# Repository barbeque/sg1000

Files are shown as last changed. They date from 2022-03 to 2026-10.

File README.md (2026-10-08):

The Soggy-1000 logo

Soggy-1000 is an open-source clone of the Sega SG-1000 home videogame system. The eventual goal of the project is to produce a copy of the SG-1000 main console, and the SK-1100 keyboard, so that the software made for the related Sega SC-3000 home computer can be preserved and enjoyed.

## License
The Soggy project is licensed under [the Creative Commons Attribution-NonCommercial 4.0 license](https://creativecommons.org/licenses/by-nc/4.0/).

If you want to build and sell a handful of these systems to use up a "minimum board order," let me know. I'll probably be okay with it!

## Sub-Projects
This repository contains multiple KiCad projects that are related to the overall Soggy project. These are:

 * `keyboard`: An implementation of the SK-1100 keyboard, using modern key switches (Under development)
 * `cartridges/romcart`: An implementation of a bare-bones (ROM-only) cartridge for SG-1000 (Tested, working)
 * `cartridges/basic-iiib`: An implementation of the SEGA BASIC Level IIIB cartridge, used for testing purposes in order to make sure cartridges can take over the entire memory map (Tested, working)

## Other Projects
Other builders have made projects that work with the Soggy! I can't take credit for them. Please visit their repos:

 * [`soggy-case`](https://github.com/kvanderlaag/soggy-case): A 3D-printed case for the Soggy v0.4 and onwards.

Thank you to everyone who has built something for the Soggy!

## Assembly Guide and BOM
Please match the BOM with the appropriate version - the files here in master are currently post-v4 improvements and some parts may be missing or changed their values when compared with the ones in `sg1000-v0.4.bom.csv`

TODO

All solder jumpers should be left as they are from fabrication. They were meant solely so that prototype features could be removed if they didn't work out instead of spinning a new board.

## Programmer's Guide
The Soggy is basically identical to the existing SG-1000, with the addition (in v0.3 and onwards) of memory mapping hardware. This hardware allows programmers to take advantage of the full 32k of main RAM on the system.

TODO: Memory map diagram

TODO: Use IOW + $10 to set it

TODO: Address will change soon to improve compatibility later

## Special Thanks
The following people helped me figure out some aspect of the SG-1000, fixed a bug in my hardware, or otherwise contributed.

 * Enri for providing [SC-3000 and SG-1000 schematics](http://www43.tok2.com/home/cmpslv/Sc3000/EnrSC.htm)
 * Chartreuse for spotting a bug with the latch responsible for page switching
 * Nick Hook from SC-3000 Survivors helped with providing diagrams, pictures, and SF-7000 information
 * Fabio Dalla Libera (sms power) helped with the M1 transistor
 * asynchronous (sms power) also helped with the M1 transistor

## Version History
# v0.5 (in development)
This version contains experimental features.

 * Wider holes on the boot ROM socket footprint, to accept a Textool/AliExpress-style ZIF socket for easier ROM changes during development
 * 1206 ferrite bead on video path to prevent colour burst noise

# v0.4 (in testing)
This version is in active development and may not be suitable for testing yet.

 * /JOY_SEL signal connected to keyboard edge, allowing keyboard 8255 to force polling of joysticks when row 7 of matrix is requested.
 * Converted to DIP Z80 from PLCC, to allow cheaper AliExpress parts to be used rather than expensive new PLCC Z80 part. New DIP Z80s are also still available from Digi-Key, Mouser, etc.
 * Debounce circuit on NMI pin using a Schmitt trigger (design from [this Tynemouth Software blog entry](http://blog.tynemouthsoftware.co.uk/2022/07/how-the-mini-pet-works-debouncing.html), thank you)
 * Weird overpour onto expansion edge fixed, as were some missing silkscreens for '574 and '04
 * Rudimentary support for Sega Genesis/Mega Drive controllers. No mode switching, so it is a similar limitation to Master System games on the Genesis.
 * Trim pot for fine tuning of TMS9918 input clock (and therefore colourburst/Z80/sound clock.) Can be replaced with a simple wire link if you are feeling brave.

# v0.3
Many new features added on the base of the v0.2, and some bugs fixed. This was intended to be the first public release, and is recommended for most people.

 * /IORD and /IOWR signals (IORQ + WR/RD) synthesized and passed to cartridge port. This prevented the SF-7000 from working, as did an I/O map collision with the keyboard. Both problems are now fixed.
 * The full 62256 SRAM is wired up, providing 32K of work RAM to the system. The first 8K are accessible without touching the memory management unit; the second 8K can be switched between four "pages." This should allow Sega BASIC and many other titles relying on SC-3000 functions to work. Previous boards had a 2K mod, matching the SC-3000, but this was not tested.
 * An onboard BIOS ROM socket has been added, which runs when a cartridge is not inserted (detected through the "B2" pin on the cartridge slot, which is usually connected to B1 inside cartridges)

Known bugs:
 * /JOY_SEL is not connected to the keyboard edge
 * Load input on memory management 74ls573 is inverted and doesn't work

# v0.2
 * SK-1100 keyboard edge connector added.
 * Sound chip-induced lockup under /M1 fixed.
 * Extremely weak video signal fixed.
 * Backwards controller ports fixed.
 * Experimental debounce cap on "pause" button added.
 * Reset button added.
 * USB power connector shield grounded.
 * Several problems with sporadic interrupts and waits fixed by adding pull-ups.

Known bugs:
 * /JOY_SEL is not connected to the keyboard edge

# v0.1
Initial release.

Known bugs:
 * Too many to list.

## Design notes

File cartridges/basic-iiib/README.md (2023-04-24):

This folder contains the kicad source files to construct a clone of the Sega SC-3000 BASIC IIIB cartridge that uses UM61512 SRAM instead of the original DRAM, which makes it also compatible with the SK-1100-equipped SG-1000.

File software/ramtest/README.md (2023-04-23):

# RAM tester
This program is meant to be burned to a cartridge ROM and run on a Soggy-1000 clone system. It runs a few simple tests, first doing a check for mirroring to establish the total amount of RAM installed into the system, and then performs a test of the Soggy's page switching functionality. It is not exhaustive nor necessarily indicative of hardware faults.

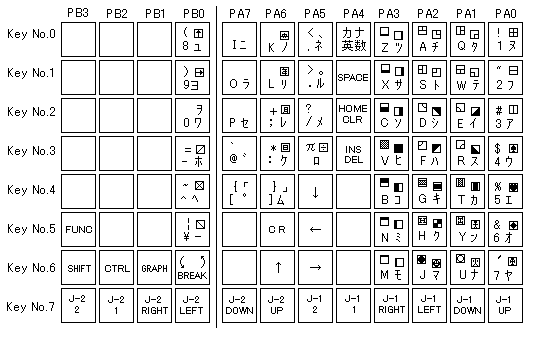
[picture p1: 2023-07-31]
software/shared/references/enri-keymatrix.png

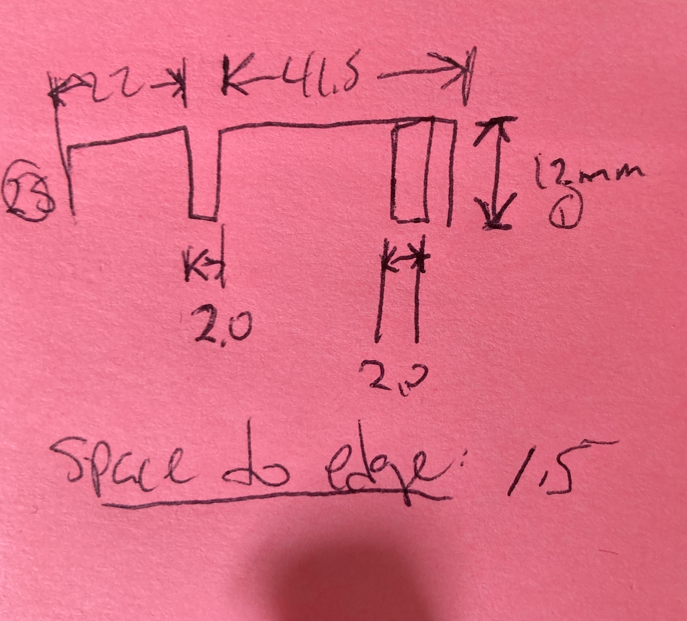
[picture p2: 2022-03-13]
References/mark-iii-expansion-edge.jpg

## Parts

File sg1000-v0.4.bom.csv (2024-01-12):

Customer Reference | Component Name | Value | Footprint | Part Number | Quantity | Description
Soggy: C1, C2 | C | 0.1µF | Capacitor_SMD:C_0805_2012Metric_Pad1.15x1.40mm_HandSolder | 1276-1099-1-ND | 2 | Unpolarized capacitor
Soggy: C3 | C_Polarized_Small_US | 22µF | Capacitor_THT:CP_Radial_D5.0mm_P2.50mm | 493-1037-ND | 1 | Polarized capacitor, small US symbol
Soggy: C4, C9, C16, C100 | C_Small | 0.1µF | Capacitor_SMD:C_0805_2012Metric_Pad1.18x1.45mm_HandSolder | 1276-1099-1-ND | 4 | Unpolarized capacitor, small symbol
Soggy: C5 | C_Polarized_Small_US | 220µF | Capacitor_THT:CP_Radial_D6.3mm_P2.50mm | 493-15121-ND | 1 | Polarized capacitor, small US symbol
Soggy: C6 | C_Polarized_Small | 10µF | Capacitor_SMD:C_0805_2012Metric_Pad1.18x1.45mm_HandSolder | 1276-1298-1-ND | 1 | Polarized capacitor, small symbol
Soggy: C7, C8 | C_Small | 33pF | Capacitor_SMD:C_0805_2012Metric_Pad1.15x1.40mm_HandSolder | 732-7817-1-ND | 2 | Unpolarized capacitor, small symbol
Soggy: CV1 | C_Trim_Small | 0-20pF | LeadedSolder:Tayda_Variable_Trimmer_Cap |  | 1 | Trimmable capacitor, small symbol
Soggy: D1 | D | D | Diode_THT:D_A-405_P7.62mm_Horizontal | 641-1310-1-ND | 1 | Diode
Soggy: D2 | LED | LED | LED_THT:LED_D3.0mm | 1497-1022-ND | 1 | Light emitting diode
Soggy: F1 | Fuse | 2A | Fuse:Fuse_0805_2012Metric_Pad1.15x1.40mm_HandSolder | 2315-FCC20202AATPCT-ND | 1 | Fuse
Soggy: J1 | USB-B1HSB6 | USB-B1HSB6 | USB-B1HSB6:OST_USB-B1HSB6 | ED2983-ND | 1
Soggy: J2 | RCJ-017 | RCJ-014 | Jacks:CUI_RCJ-017 | CP-1403-ND‎ | 1
Soggy: J3 | RCJ-017 | RCJ-013 | Jacks:CUI_RCJ-017 | CP-1402-ND‎ | 1
Soggy: JOY1, JOY2 | DB9_Female | DB9_Female | LeadedSolder:A-DS 09 A-KG-T2S | AE10968-ND | 2 | 9-pin female D-SUB connector
Soggy: Q1 | Q_NPN_EBC | 2n4401 | Package_TO_SOT_THT:TO-92_Inline_Wide | 2N4401TFCT-ND | 1 | NPN transistor, emitter/base/collector
Soggy: Q1c1 | Q_PNP_EBC | 2n3906 | Package_TO_SOT_THT:TO-92_Inline_Wide | 641-1946-ND | 1 | PNP transistor, emitter/base/collector
Soggy: R1 | R_Small_US | 100Ω | Resistor_SMD:R_0805_2012Metric_Pad1.15x1.40mm_HandSolder | RMCF0805JT100RCT-ND | 1 | Resistor, small US symbol
Soggy: R2, R9 | R_Small_US | 560Ω | Resistor_SMD:R_0805_2012Metric_Pad1.20x1.40mm_HandSolder | RMCF0805JT560RCT-ND | 2 | Resistor, small US symbol
Soggy: R3 | R_Small_US | 47kΩ | Resistor_SMD:R_0805_2012Metric_Pad1.15x1.40mm_HandSolder | RMCF0805JT47K0CT-ND | 1 | Resistor, small US symbol
Soggy: R4 | R_Small_US | 1kΩ | Resistor_SMD:R_0805_2012Metric_Pad1.15x1.40mm_HandSolder | RMCF0805FT1K00CT-ND | 1 | Resistor, small US symbol
Soggy: R7 | R_Small_US | 0Ω | Resistor_SMD:R_0805_2012Metric_Pad1.20x1.40mm_HandSolder | RMCF0805ZT0R00CT-ND | 1 | Resistor, small US symbol
Soggy: R8 | R_Small_US | 1MΩ | Resistor_SMD:R_0805_2012Metric_Pad1.15x1.40mm_HandSolder | RMCF0805JT1M00CT-ND | 1 | Resistor, small US symbol
Soggy: R10, R12 | R_Small_US | 1kΩ | Resistor_SMD:R_0805_2012Metric_Pad1.20x1.40mm_HandSolder | RMCF0805FT1K00CT-ND | 2 | Resistor, small US symbol
Soggy: R11 | R_Small_US | 470Ω | Resistor_SMD:R_0805_2012Metric_Pad1.20x1.40mm_HandSolder | RMCF0805JT470RCT-ND | 1 | Resistor, small US symbol
Soggy: R13, R15 | R_Small_US | 330Ω | Resistor_SMD:R_0805_2012Metric_Pad1.15x1.40mm_HandSolder | RMCF0805JT330RCT-ND | 2 | Resistor, small US symbol
Soggy: R14 | R_Small_US | 75Ω | Resistor_SMD:R_0805_2012Metric_Pad1.20x1.40mm_HandSolder | RMCF0805JT75R0CT-ND | 1 | Resistor, small US symbol
Soggy: R16, R17, R18, R21 | R_Small_US | 10kΩ | Resistor_SMD:R_0805_2012Metric_Pad1.20x1.40mm_HandSolder | 311-10KARCT-ND | 4 | Resistor, small US symbol
Soggy: R19, R20, R23 | R_Small_US | 47kΩ | Resistor_SMD:R_0805_2012Metric_Pad1.20x1.40mm_HandSolder | RMCF0805JT47K0CT-ND | 3 | Resistor, small US symbol
Soggy: R22 | R_Small_US | 100kΩ | Resistor_SMD:R_0805_2012Metric_Pad1.20x1.40mm_HandSolder | RMCF0805FT100KCT-ND | 1 | Resistor, small US symbol
Soggy: RN1, RN2 | R_Network06_US | 4.7kΩ | Resistor_THT:R_Array_SIP7 | 4607X-101-472LF-ND | 2 | 6 resistor network, star topology, bussed resistors, small US symbol
Soggy: SW1 | SW_SPST | Pause Key | Button_Switch_THT:SW_PUSH_6mm | 679-2428-ND | 1 | Single Pole Single Throw (SPST) switch
Soggy: SW2 | SW_Push | Power Toggle | LeakyChips:PVA1_Switch | 401-1132-ND | 1 | Push button switch, generic, two pins
Soggy: SW3 | SW_Push | Reset Key | Button_Switch_THT:SW_PUSH_6mm | 679-2428-ND | 1 | Push button switch, generic, two pins
Soggy: U1 | SG-1000-Cart | SG-1000-Cart | LeadedSolder:SG1000_Cart | 151-1435-ND | 1
Soggy: U3 | SN76489AN | SN76489AN | Package_DIP:DIP-16_W7.62mm_LongPads | AE9992-ND | 1
Soggy: U4, U16 | 74LS32 | 74LS32 | Package_DIP:DIP-14_W7.62mm_LongPads | 296-36151-5-ND | 2 | Quad 2-input OR
Soggy: U5 | 27C256 | 27C256 | Package_DIP:DIP-28_W15.24mm |  | 1 | OTP EPROM 256 KiBit
Soggy: U6 | 74LS573 | 74LS573 | Package_DIP:DIP-20_W7.62mm_Socket_LongPads | DM74LS573N-ND | 1 | 8-bit Latch 3-state outputs
Soggy: U7 | 74LS00 | 74LS00 |  | 296-1626-ND | 1 | quad 2-input NAND gate
Soggy: U9 | Z80CPU | Z80CPU | Package_DIP:DIP-40_W15.24mm_Socket_LongPads |  | 1 | 8-bit General Purpose Microprocessor, DIP-40
Soggy: U11, U103 | AS6C62256-DIP | AS6C62256-DIP | Package_DIP:DIP-28_W15.24mm_Socket_LongPads | 1450-1033-ND | 2
Soggy: U12 | TMS9918A | TMS9918A | Package_DIP:DIP-40_W15.24mm_Socket_LongPads | ED3048-5-ND | 1
Soggy: U13 | 74LS139 | 74LS139 | Package_DIP:DIP-16_W7.62mm_LongPads | 296-1640-5-ND | 1 | Dual Decoder 1 of 4, Active low outputs
Soggy: U17 | 74LS14 | 74LS14 | Package_DIP:DIP-14_W7.62mm_Socket_LongPads | 296-1643-5-ND | 1 | Hex inverter schmitt trigger
Soggy: U18, U21 | 74LS257 | 74LS257 | Package_DIP:DIP-16_W7.62mm_Socket_LongPads | ‎296-1656-5-ND‎ | 2 | Quad 2 to 1 Multiplexer
Soggy: U99 | 74HCT04 | 74HCT04 | Package_DIP:DIP-14_W7.62mm_Socket_LongPads | 296-2083-5-ND | 1 | Hex Inverter
Soggy: U100, U101, U102 | 74HCT574 | 74HCT574 | Package_DIP:DIP-20_W7.62mm_Socket_LongPads | 296-2129-5-ND | 3 | 8-bit Register, 3-state outputs
Soggy: X2 | Crystal | 10.73863MHz | Crystal:Crystal_HC49-U_Vertical | X1062-ND | 1 | Two pin crystal

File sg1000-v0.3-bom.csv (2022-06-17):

Customer Reference | Component Name | Value | Footprint | Part Number | Quantity | Description
Soggy-v3: C1, C2 | C | 0.1µF | Capacitor_SMD:C_0805_2012Metric_Pad1.15x1.40mm_HandSolder | 1276-1099-1-ND | 2 | Unpolarized capacitor
Soggy-v3: C3 | C_Polarized_Small_US | 22µF | Capacitor_THT:CP_Radial_D5.0mm_P2.50mm | 493-1037-ND | 1 | Polarized capacitor, small US symbol
Soggy-v3: C4, C9, C100 | C_Small | 0.1µF | Capacitor_SMD:C_0805_2012Metric_Pad1.18x1.45mm_HandSolder | 1276-1099-1-ND | 3 | Unpolarized capacitor, small symbol
Soggy-v3: C5 | C_Polarized_Small_US | 220µF | Capacitor_THT:CP_Radial_D6.3mm_P2.50mm | 493-15121-ND | 1 | Polarized capacitor, small US symbol
Soggy-v3: C6 | CP_Small | 10µF | Capacitor_SMD:C_0805_2012Metric_Pad1.15x1.40mm_HandSolder | 1276-1298-1-ND | 1
Soggy-v3: C7, C8 | C_Small | 33pF | Capacitor_SMD:C_0805_2012Metric_Pad1.15x1.40mm_HandSolder | 732-7817-1-ND | 2 | Unpolarized capacitor, small symbol
Soggy-v3: C10 | C_Small | 10µF | Capacitor_SMD:C_0805_2012Metric_Pad1.18x1.45mm_HandSolder | 1276-1298-1-ND | 1 | Unpolarized capacitor, small symbol
Soggy-v3: CN1 | Conn_01x07_Female | Conn_01x07_Female | Connector_PinHeader_2.54mm:PinHeader_1x07_P2.54mm_Vertical |  | 1 | Generic connector, single row, 01x07, script generated (kicad-library-utils/schlib/autogen/connector/)
Soggy-v3: D1 | D | D | Diode_THT:D_A-405_P7.62mm_Horizontal | 641-1310-1-ND | 1 | Diode
Soggy-v3: D2 | LED | LED | LED_THT:LED_D3.0mm | 1497-1022-ND | 1 | Light emitting diode
Soggy-v3: F1 | Fuse | 2A | Fuse:Fuse_0805_2012Metric_Pad1.15x1.40mm_HandSolder | 2315-FCC20202AATPCT-ND | 1 | Fuse
Soggy-v3: J1 | USB-B1HSB6 | USB-B1HSB6 | OST_USB-B1HSB6 | ED2983-ND | 1
Soggy-v3: J2 | RCJ-017 | RCJ-014 | CUI_RCJ-017 | CP-1403-ND | 1
Soggy-v3: J3 | RCJ-017 | RCJ-013 | CUI_RCJ-017 | CP-1402-ND | 1
Soggy-v3: JOY1, JOY2 | DB9_Female | DB9_Female | LeadedSolder:A-DS 09 A-KG-T2S | AE10968-ND | 2 | 9-pin female D-SUB connector
Soggy-v3: Q1 | Q_NPN_EBC | 2n4401 | Package_TO_SOT_THT:TO-92_Inline_Wide | 2N4401TFCT-ND | 1 | NPN transistor, emitter/base/collector
Soggy-v3: Q1c1 | Q_PNP_EBC | 2n3906 | Package_TO_SOT_THT:TO-92_Inline_Wide | 641-1946-ND | 1 | PNP transistor, emitter/base/collector
Soggy-v3: R1, R6 | R_Small_US | 100Ω | Resistor_SMD:R_0805_2012Metric_Pad1.15x1.40mm_HandSolder | RMCF0805JT100RCT-ND | 2 | Resistor, small US symbol
Soggy-v3: R2, R9 | R_Small_US | 560Ω | Resistor_SMD:R_0805_2012Metric_Pad1.20x1.40mm_HandSolder | RMCF0805JT560RCT-ND | 2 | Resistor, small US symbol
Soggy-v3: R3, R5 | R_Small_US | 47kΩ | Resistor_SMD:R_0805_2012Metric_Pad1.15x1.40mm_HandSolder | RMCF0805JT47K0CT-ND | 2 | Resistor, small US symbol
Soggy-v3: R4, R10, R12 | R_Small_US | 1kΩ | Resistor_SMD:R_0805_2012Metric_Pad1.15x1.40mm_HandSolder | RMCF0805FT1K00CT-ND | 3 | Resistor, small US symbol
Soggy-v3: R7 | R_Small_US | 0Ω | Resistor_SMD:R_0805_2012Metric_Pad1.20x1.40mm_HandSolder | RMCF0805ZT0R00CT-ND | 1 | Resistor, small US symbol
Soggy-v3: R8 | R_Small_US | 1MΩ | Resistor_SMD:R_0805_2012Metric_Pad1.15x1.40mm_HandSolder | RMCF0805JT1M00CT-ND | 1 | Resistor, small US symbol
Soggy-v3: R11 | R_Small_US | 470Ω | Resistor_SMD:R_0805_2012Metric_Pad1.20x1.40mm_HandSolder | RMCF0805JT470RCT-ND | 1 | Resistor, small US symbol
Soggy-v3: R13, R15 | R_Small_US | 330Ω | Resistor_SMD:R_0805_2012Metric_Pad1.15x1.40mm_HandSolder | RMCF0805JT330RCT-ND | 2 | Resistor, small US symbol
Soggy-v3: R14 | R_Small_US | 75Ω | Resistor_SMD:R_0805_2012Metric_Pad1.20x1.40mm_HandSolder | RMCF0805JT75R0CT-ND | 1 | Resistor, small US symbol
Soggy-v3: R16, R17 | R_Small_US | 10kΩ | Resistor_SMD:R_0805_2012Metric_Pad1.20x1.40mm_HandSolder | RMCF0805JT10K0CT-ND | 2 | Resistor, small US symbol
Soggy-v3: RN1, RN2 | R_Network06_US | 4.7kΩ | Resistor_THT:R_Array_SIP7 | 4607X-101-472LF-ND | 2 | 6 resistor network, star topology, bussed resistors, small US symbol
Soggy-v3: SP1 | 74LS00 | 74LS00 | Package_DIP:DIP-14_W7.62mm |  | 1 | quad 2-input NAND gate
Soggy-v3: SW1 | SW_SPST | Pause Key | Button_Switch_THT:SW_PUSH_6mm | 679-2428-ND | 1 | Single Pole Single Throw (SPST) switch
Soggy-v3: SW2 | SW_Push | Power Toggle | LeakyChips:PVA1_Switch | 401-1132-ND | 1 | Push button switch, generic, two pins
Soggy-v3: SW3 | SW_Push | Reset Key | Button_Switch_THT:SW_PUSH_6mm | 679-2428-ND | 1 | Push button switch, generic, two pins
Soggy-v3: TP1 | TestPoint | ~{HALT} | TestPoint:TestPoint_Pad_1.0x1.0mm |  | 1 | test point
Soggy-v3: TP2 | TestPoint | +5V | TestPoint:TestPoint_Loop_D1.80mm_Drill1.0mm_Beaded |  | 1 | test point
Soggy-v3: TP3 | TestPoint | GND | TestPoint:TestPoint_Loop_D1.80mm_Drill1.0mm_Beaded |  | 1 | test point
Soggy-v3: TP4 | TestPoint | ~{NMI} | TestPoint:TestPoint_Pad_1.0x1.0mm |  | 1 | test point
Soggy-v3: U1 | SG-1000-Cart | SG-1000-Cart | LeadedSolder:SG1000_Cart | 151-1435-ND | 1
Soggy-v3: U2 | SG-1000-Expansion | SG-1000-Expansion | LeadedSolder:SG1000_Edge |  | 1
Soggy-v3: U3 | SN76489AN | SN76489AN | Package_DIP:DIP-16_W7.62mm_LongPads | AE9992-ND | 1
Soggy-v3: U4, U16 | 74LS32 | 74LS32 | Package_DIP:DIP-14_W7.62mm_LongPads | 296-36151-5-ND | 2 | Quad 2-input OR
Soggy-v3: U10 | PLCCZ80 | PLCCZ80 | Package_LCC:PLCC-44_THT-Socket | 2057-PLCC-44-AT-ND | 1 | Chip-carrier PLCC version of the Zilog Z80
Soggy-v3: U10 | PLCCZ80 | PLCCZ80 | Package_LCC:PLCC-44_THT-Socket | 269-3899-ND | 1 | Chip-carrier PLCC version of the Zilog Z80
Soggy-v3: U11, U103 | AS6C62256-DIP | AS6C62256-DIP | Package_DIP:DIP-28_W15.24mm_Socket_LongPads | 1450-1033-ND | 2
Soggy-v3: U12 | TMS9918A | TMS9918A | Package_DIP:DIP-40_W15.24mm_Socket_LongPads | ED3048-5-ND | 1
Soggy-v3: U13 | 74LS139 | 74LS139 | Package_DIP:DIP-16_W7.62mm_LongPads | 296-1640-5-ND | 1 | Dual Decoder 1 of 4, Active low outputs
Soggy-v3: U18, U21 | 74LS257 | 74LS257 | Package_DIP:DIP-16_W7.62mm_Socket_LongPads | 296-1656-5-ND | 2 | Quad 2 to 1 Multiplexer
Soggy-v3: U99 | 74HCT04 | 74HCT04 | Package_DIP:DIP-14_W7.62mm | 296-2083-5-ND | 1 | Hex Inverter
Soggy-v3: U100, U101, U102 | 74HCT574 | 74HCT574 | Package_DIP:DIP-20_W7.62mm | 296-2129-5-ND | 3 | 8-bit Register, 3-state outputs
Soggy-v3: X2 | Crystal | 10.73863MHz | Crystal:Crystal_HC49-U_Vertical | X1062-ND | 1 | Two pin crystal

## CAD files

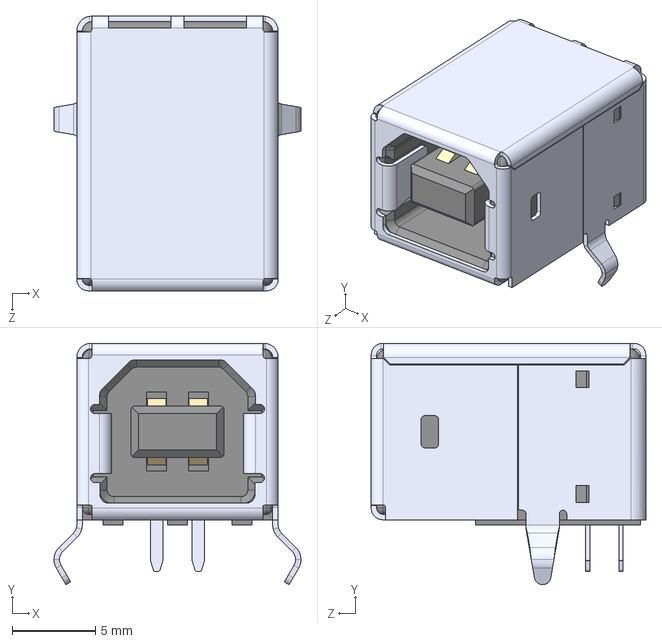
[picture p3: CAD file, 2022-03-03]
USB-B1HSB6/USB-B1HSB6.step
14.8 x 14.5 x 16.5 mm

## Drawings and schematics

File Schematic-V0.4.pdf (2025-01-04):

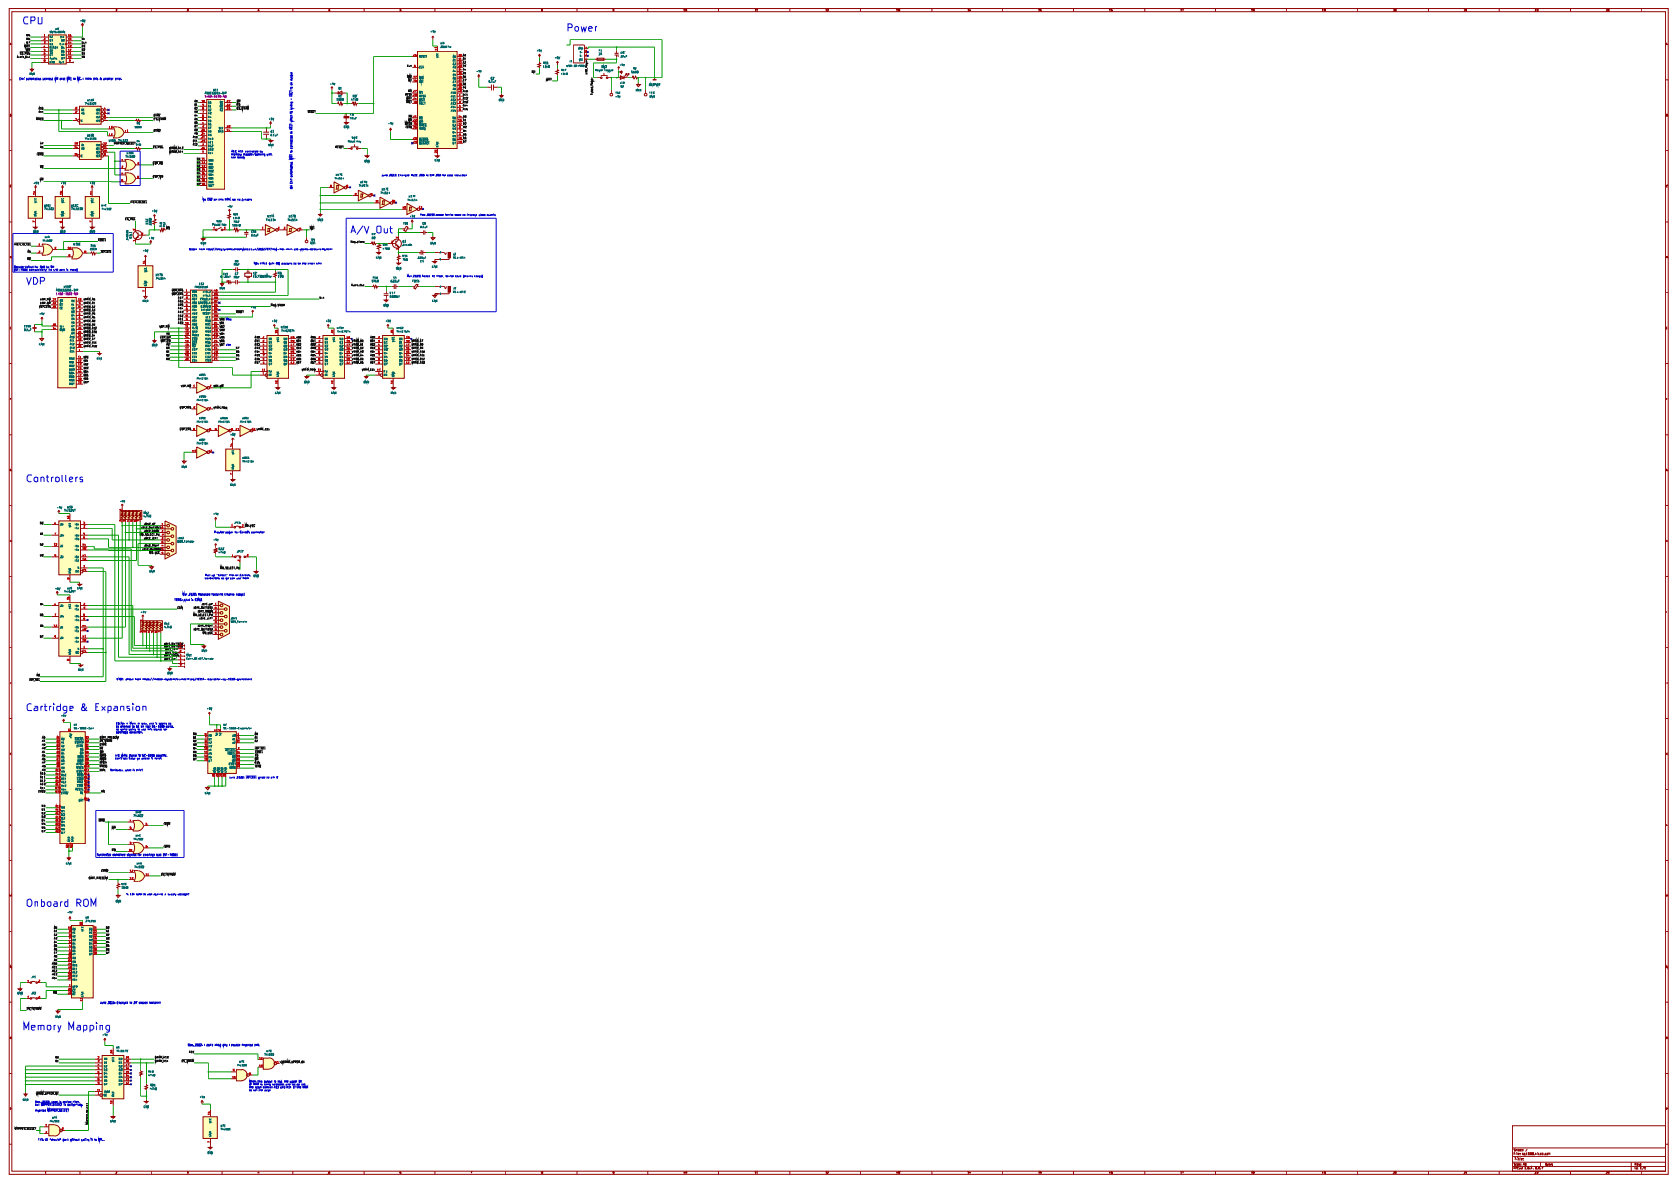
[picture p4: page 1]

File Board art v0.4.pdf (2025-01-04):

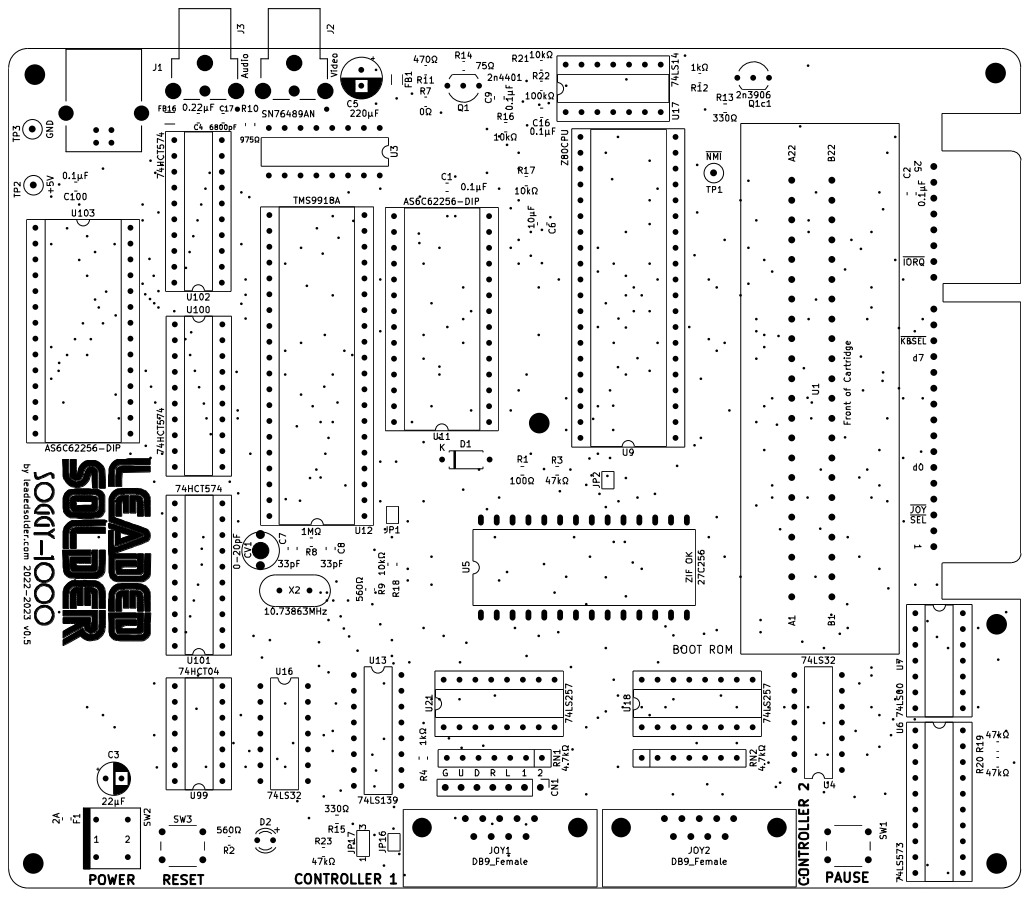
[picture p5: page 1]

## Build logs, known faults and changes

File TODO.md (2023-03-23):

- [x] export SN76489 symbol from leako, and import it into here and the global lib storage
- [x] add the address, I/O decoders
- [x] check the write pin on the RAM
- [x] add the TMS9918
- [x] ...and the DRAM-SRAM intercept flipflops
- [x] make a symbol for the cart slot
- [x] make a footprint for the cart slot part
- [x] will the power transistor setup from leako work?
- [x] populate all the z80 pins with labels
- [x] double check NMI transistor pinout, use a PNP i already stock (3906?)
- [x] copy digikey pn from leako for 6mm push button
- [x] what size of resistor should i use? looks like i started out with 0805 again for capacitors, i guess we're doing 0805 again here
- [x] confirm the weirdness with /WR or WR for /WE on 76489
- [x] finish switching to the cypress THT 62256 since i already have some?
- [x] copy video and audio output circuits from leako
- [x] double check the decoder weave for the controllers
- [x] find 74ls257
- [x] usb power input (with power flags)
- [x] power switch
- [x] add a spare footprint for an emergency inverter
- [x] cart slot is actually 0.125"
- [x] print and check cartridge interference once parts arranged
- [x] stuff all this into a board and route it
- [x] keyboard port? what's it even look like
- [ ] maybe do the flange and mounting holes on the cart slot after all
- [X] make a decision on 150x150 - it's only 78 cents more per board and i don't think anyone cares
- [x] make room for mounting holes
- [x] either find a new cartridge slot or make sure parts aren't hitting the mounting holes - YES - EDAC 396-044-520-201
- [x] [SF-7000] look into the sf-7000 i/o range that fabiodl mentioned - "The sg-1000 does not allow connecting the SF-7000 because the joystick/SK1100 takes the IO range 0XC0-0XFF, while the SF-7000 requires the range 0xE0~0xFF."
- [x] [SF-7000] defeat keyboard/joystick decode if a5 is high
- [x] [SF-7000] synthesize /IOWR and /IORD and pass to cartridge
- [x] wire at least 2k (SG-1000 II) of the 32k 62256
- [x] [Onboard ROM] wire up onboard DIP ROM
- [x] [Onboard ROM] detect non-presence of cartridge
- [x] [Onboard ROM] decode EXM2 to onboard ROM if cartridge is not present
- [x] [Memory Mapper] 74ls74 set
- [x] [Memory Mapper] decode a read to upper 8k of RAM specially (trigger on a13 & /CS_WRAM maybe using a quad nand)
- [x] [Memory Mapper] replace 74ls74 with a different latch that emits only during upper-8k read (7474 is not tristate) - picked 74ls373, see if something better comes along
- [x] [Memory Mapper] Dump all the knowledge we have about the memory map into decody to make sure we actually have a 16k window, and not 32k. If we have 32k, just get rid of the mapper.
- [x] [Memory Mapper] does it make sense to use a '573 instead of a '373? Might be easier to route and find
- [x] [Memory Mapper] find a spot on the board for it
- [ ] [Keyboard] Find out if it is possible to get 6u spacebars or if 6.25u is needed
- [x] [Software] RAM tester, in Z80 assembly so we can control the RAM.
- [x] Build a clone of the BASIC III-B cartridge to ensure /CS_WRAM pullup works
- [x] 24kHz LPF on audio output
- [x] better cap (0.22uF film?) on audio output

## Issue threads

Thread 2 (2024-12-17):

Is there an 3D printable case available?

xrip, 2024-12-17:
First of all i would like to thank you for such a wonderful project! Soldered it few dayas ago and it's absolutely lovely piece of hardware!

Now, i'm trying to find an 3d printable case for it, just because Soggy deserves it! I saw your post on reddit where you have nice red case, may be you can share 3d project for it?

Btw, i'm going to upgrade Soggy to make it Sega Master System compatible, i have written SG1000/SMS emulator on my own, and now i'm adding support of SMS mode 4 to https://github.com/visrealm/pico9918

I've also substitutes ROM with RP2040

kvanderlaag, 2024-12-17:
@xrip the case posted on Reddit is mine; you can find it here: https://github.com/kvanderlaag/soggy-case

barbeque, 2024-12-17:
I wanted to try and integrate the Pico9918 in order to save a few chips on the Soggy, so I'm really excited to see how well this will work! Especially with Mode 4 features. Please keep us updated.

xrip, 2024-12-17:
My current setup is rp2040 as rom(cartridge) and ram emulator. It works fine, also it can handle joystick input if needed,  just teo wires from /mem /wr and /io

barbeque, 2024-12-17:
Very cool! I started on a Pico-based cartridge for the PC-6001 but quickly ran out of lines on the RP2040. I am going to try address/data multiplexing with a 245

xrip, 2024-12-18:
I have omited 245 level shifters and RP2040 works fine, but it's for home use, not for something i can share with others :)
Regarding 165 (and onthers) multiplexors - looks like speed penalty with them are cruicial, you loose time with reading and handling - delays seems to be so long.

xrip, 2024-12-25:
Btw, may be it worth adding to readme.md
https://www.printables.com/model/828077-sega-sg-1000-sj-200-controller-shell
printable original joystic shell

Closed 2025-08-19.

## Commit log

2020-03-27 SG-1000 initial commit - RAM and CPU
    [sg1000.kicad_pcb, sg1000.sch]
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2022-02-23 NMI transistor replaced
    [sg1000.sch]
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2022-02-24 TMS9918 is dropped onto the board
    [sg1000.sch]
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2022-03-03 Power supply, cart slot
    [USB-B1HSB6.step, sg1000.kicad_pcb, sg1000.kicad_sch]
2022-03-03 Layout started, and abandoned for now
    [sg1000.kicad_pcb]
2022-03-03 I'm gonna need an outline before we continue
    [sg1000.kicad_pcb, sg1000.kicad_sch]
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2022-03-05 Add A11 jumper so we can maybe get 2k
    [sg1000.kicad_pcb, sg1000.kicad_sch]
2022-03-05 This routing is gonna kill me
    [sg1000.kicad_pcb, sg1000.kicad_sch]
2022-03-05 Starting route all over again
    [sg1000.kicad_pcb]
2022-03-06 Most of the route done
    [sg1000.kicad_pcb]
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2022-03-06 Fully routed, before cleanup
    [sg1000.kicad_pcb]
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2022-03-11 Turn the controller ports around so you can use them
    [sg1000.kicad_pcb, sg1000.kicad_sch]
2022-03-13 Expansion footprint, sort of
    [sg1000.kicad_sch]
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2022-03-14 Bevel and edge cleanup
    [sg1000.kicad_pcb]
2022-03-24 Additional mounting hole vaguely halfway
    [sg1000.kicad_pcb]
2022-03-24 Logo bigger for easier silk
    [sg1000.kicad_pcb]
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2022-03-25 Fix many pin warnings
    [sg1000.kicad_pcb, sg1000.kicad_sch]
2022-03-25 Fix diode size
    [sg1000.kicad_pcb, sg1000.kicad_sch]
2022-03-29 Fix /EXM2 being severed from cart
    [sg1000.kicad_pcb, sg1000.kicad_sch]
2022-03-30 Add test-points for 5V, GND logic probe
    [sg1000.kicad_pcb, sg1000.kicad_sch]
2022-03-30 CSCN4 doesn't exist on SG-1000
    [sg1000.kicad_pcb, sg1000.kicad_sch]
2022-03-30 Add NMI test point
    [sg1000.kicad_pcb, sg1000.kicad_sch]
2022-03-30 /HALT is an error
    [sg1000.kicad_sch]
2022-03-30 Add pull-ups for /INT, /WAIT
    [sg1000.kicad_pcb, sg1000.kicad_sch]
2022-03-30 Remove jumpers and hardwire /EXM2
    [sg1000.kicad_pcb, sg1000.kicad_sch]
2022-03-30 Before fixing video
    [sg1000.kicad_sch]
2022-03-30 Fix composite video output
    [sg1000.kicad_pcb, sg1000.kicad_sch]
2022-03-30 Flip CN1 left/right
    [sg1000.kicad_pcb, sg1000.kicad_sch]
2022-04-01 Finally use /CE instead of /OE
    [sg1000.kicad_sch]
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2022-04-01 Tag important fields of the z80
    [sg1000.kicad_pcb]
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2022-04-01 Woops, NMI already had a pull-up
    [sg1000.kicad_pcb, sg1000.kicad_sch]
2022-04-05 Use kamillebidan's design for sound enable
    [sg1000.kicad_pcb, sg1000.kicad_sch]
2022-04-06 Pause debounce cap (optional)
    [sg1000.kicad_pcb, sg1000.kicad_sch]
2022-04-08 Begin work on v0.3
    [sg1000.kicad_pcb]
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2022-04-09 Wire a11 on the WRAM so we now have 2k
    [sg1000.kicad_pcb, sg1000.kicad_sch]
2022-04-14 ROM cart v0.1
    Squashed commit of the following:
    commit 099f3d5905d9a519f42521b6d90e9502632c3156
    Author: mike <barbeque@users.noreply.github.com>
    Date: Wed Apr 13 22:38:05 2022 -0600
    ROM cart v0.1 submitted to JLCPCB
    commit 5ab6b7ac412f84d53a05512d3693885756388d7a
    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
    [romcart.kicad_pcb, romcart.kicad_sch, sg1000.kicad_pcb]
2022-04-16 Provide 1.6mm clearance for fingers so bevel is easier
    [romcart.kicad_pcb]
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2022-04-25 Try to make board as wide as keyboard conn, 6mm keepout
    [romcart.kicad_pcb, sg1000.kicad_pcb]
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2022-04-26 Memory-mapping unit to enable full 32k of work-RAM.
    commit 0013c7aeb5d87dec324f5a873a4d234bb1e2ce9e
    Date: Mon Apr 25 20:37:28 2022 -0600
    Labels for the major pins on the MMU
    commit 6e9c207284909a7267ee1152d3638d1574f771a7
    Date: Mon Apr 25 20:28:16 2022 -0600
    Clean up silks for RCJs
    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
    [sg1000.kicad_pcb, sg1000.kicad_sch]
2022-04-27 Use socket DIP footprint for bigger pads
    [sg1000.kicad_pcb, sg1000.kicad_sch]
2022-04-29 Added Keyboard Layout Editor fantasy layout
    [sg1000.kicad_pcb]
2022-04-30 Use big hole ZIF-style socket from BBC for ROM
    [sg1000.kicad_pcb, sg1000.kicad_sch]
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2022-05-07 v0.3 sent to fab
    [sg1000.kicad_pcb, sg1000.kicad_sch]
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2022-05-20 BASIC Level IIIB clone cart
    [basic3.kicad_pcb, basic3.kicad_sch, romcart.kicad_pcb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]
2022-05-31 Fix weird overpour onto keyboard edge
    [sg1000.kicad_pcb]
2022-06-03 Fix u99 silkscreen
    [sg1000.kicad_pcb]
2022-06-11 Jumper instructions on IIIB cart
    [basic3.kicad_pcb]
2022-06-14 Turn the 74'574 silks back on
    [sg1000.kicad_pcb]
2022-06-17 Fix BOM prefix
    [sg1000-v0.3-bom.csv, sg1000.kicad_pcb, sg1000.kicad_sch]
2022-06-27 Convert from PLCC z80 to DIP z80
    [sg1000.kicad_pcb, sg1000.kicad_sch]
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2022-07-04 Stolen MiniPET debounce circuit for /NMI
    [sg1000.kicad_pcb, sg1000.kicad_sch]
2022-08-15 Keyboard detection in ramtest
    [sg1000.kicad_sch]
2022-10-23 Add power to controller for MD controllers
    [romcart.kicad_pcb, sg1000.kicad_pcb, sg1000.kicad_sch]
2022-10-23 Beef up trace width for controller power
    [sg1000.kicad_pcb]
2022-10-23 Give Enri overdue credit
    [sg1000.kicad_pcb]
2022-11-09 Update README to include Genesis stuff
    [sg1000.kicad_pcb]
2022-11-09 Ground unused Schmitt trigger inputs
    [sg1000.kicad_pcb, sg1000.kicad_sch]
2022-11-21 Trim cap for clock crystal
    [sg1000.kicad_pcb, sg1000.kicad_sch]
2022-12-06 Fix MAPPER_SELECT never loading the 574
    [sg1000.kicad_sch]
2022-12-06 Use inverted MAPPER_SEL
    [sg1000.kicad_pcb]
2022-12-07 ACTUALLY invert mapper_sel instead of inverting it back again
    [sg1000.kicad_pcb, sg1000.kicad_sch]
2022-12-07 Move thanks to other end of board
    [sg1000.kicad_pcb]
2022-12-09 Remove kicad5 project, schematic files
    [sg1000.sch]
2022-12-28 Move unused '04 pin to cuttable trace
    [sg1000.kicad_pcb]
2023-01-12 Fix reset capacitor error
    [sg1000.kicad_pcb, sg1000.kicad_sch]
2023-01-12 Fix missing DigiKey part numbers for BOM
    [sg1000.kicad_sch]
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2023-01-12 Release v0.4 to JLCPCB
    [sg1000.kicad_pcb]
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2023-01-31 Version of the SG-1000 cart that fits into a Mark III cartridge shell
    [mark-iii-romcart.kicad_pcb, mark-iii-romcart.kicad_sch]
2023-02-07 V2 of Mark III cart: 27c64 support without bodge
    [mark-iii-romcart.kicad_pcb, mark-iii-romcart.kicad_sch]
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2023-02-10 Force footprint on U7
    [sg1000.kicad_sch]
2023-02-10 0805 10k and 100k part numbers
    [sg1000-v0.4.bom.csv]
2023-02-11 Digi-Key part numbers for 10k, 100k that were missing them
    [sg1000.kicad_sch]
2023-02-21 Add ferrite bead to video path
    [sg1000.kicad_pcb, sg1000.kicad_sch]
2023-02-28 Mark III cart: make holes bigger, move outward 1/2-mm
    [mark-iii-romcart.kicad_pcb]
2023-03-06 Bigger test points for +5V and GND
    [sg1000.kicad_pcb, sg1000.kicad_sch]
2023-03-07 XTAL1 mystery solved
    [sg1000.kicad_sch]
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2023-03-07 SG-1000 II doesn't have 2k
    [sg1000.kicad_sch]
2023-03-23 Line up Pause and Reset
    [sg1000.kicad_pcb]
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2024-01-12 Fix digikey bag callouts for Soggy
    [sg1000-v0.4.bom.csv]
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2025-01-27 Fix NMI bug, potentially
    [sg1000.kicad_pcb, sg1000.kicad_sch]
